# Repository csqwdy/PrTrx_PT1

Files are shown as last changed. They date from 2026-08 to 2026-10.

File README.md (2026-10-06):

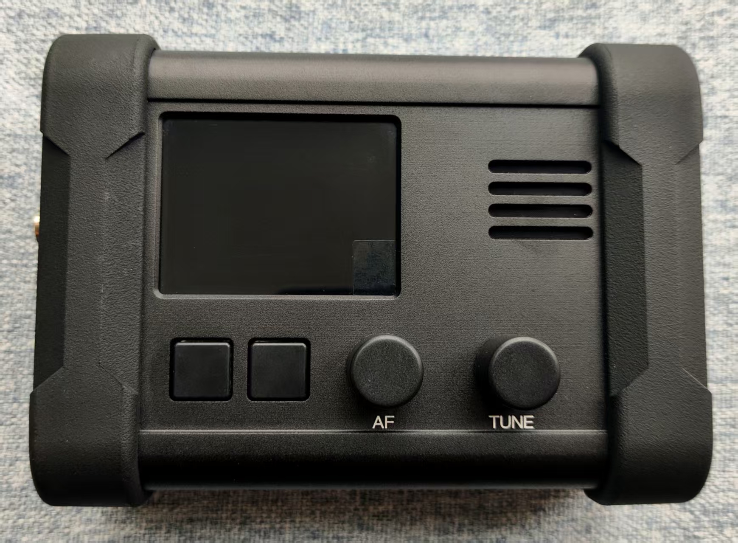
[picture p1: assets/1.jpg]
PrTrx PT正面

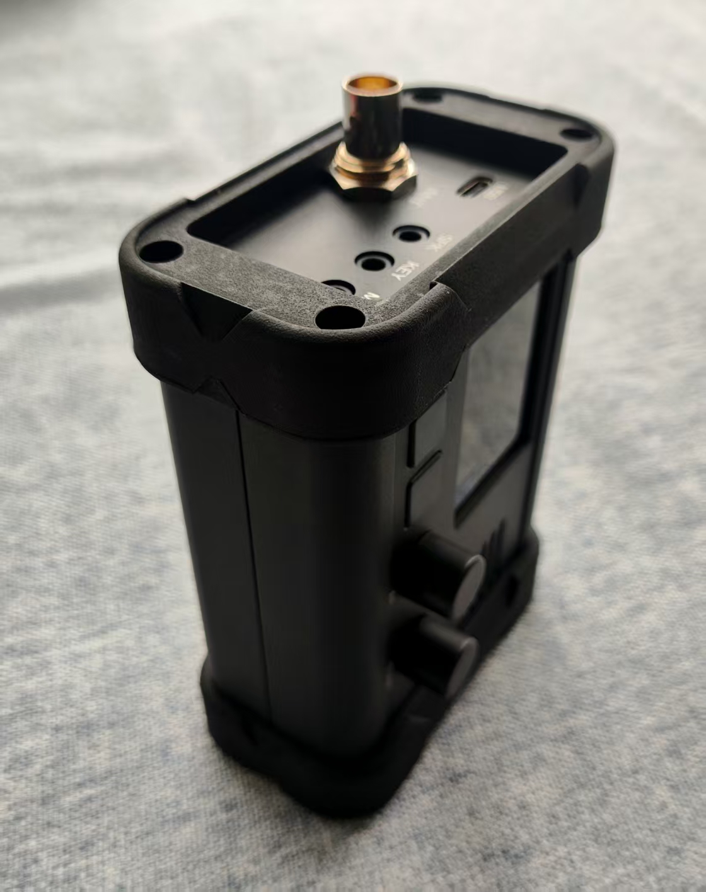
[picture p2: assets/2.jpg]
PrTrx PT正面2


PrTrx PT1 便携式QRP SDR短波电台 开源项目说明
 
一、项目简介
1. PrTrx PT1 是一款紧凑型便携式 QRP SDR 架构业余无线电收发电台。本项目为硬件完全开源、软件闭源授权 的准商业电台性能的开源项目。部分硬件与软件设计参考源自 VK7IAN 开源项目 MBPTRX，且已获得 VK7IAN 正式授权，允许基于 MBPTRX 架构进行二次开发，并允许将部分衍生软件源码进行闭源商用化落地使用。
2. PrTrx PT1 基于 Raspberry Pi Pico2（RP2350）主控的QSD正交采样检波 + QSE正交调制发射 SDR架构。频率覆盖3.5MHz - 30MHz业余无线电短波波段；具备SSB、CW、AM、FM模式；28KHz频谱和瀑布图、降噪NR、噪声消隐NB、陷波Notch滤波器；2.0寸320*240分辨率高清IPS液晶显示屏；
 架构及参数如下：
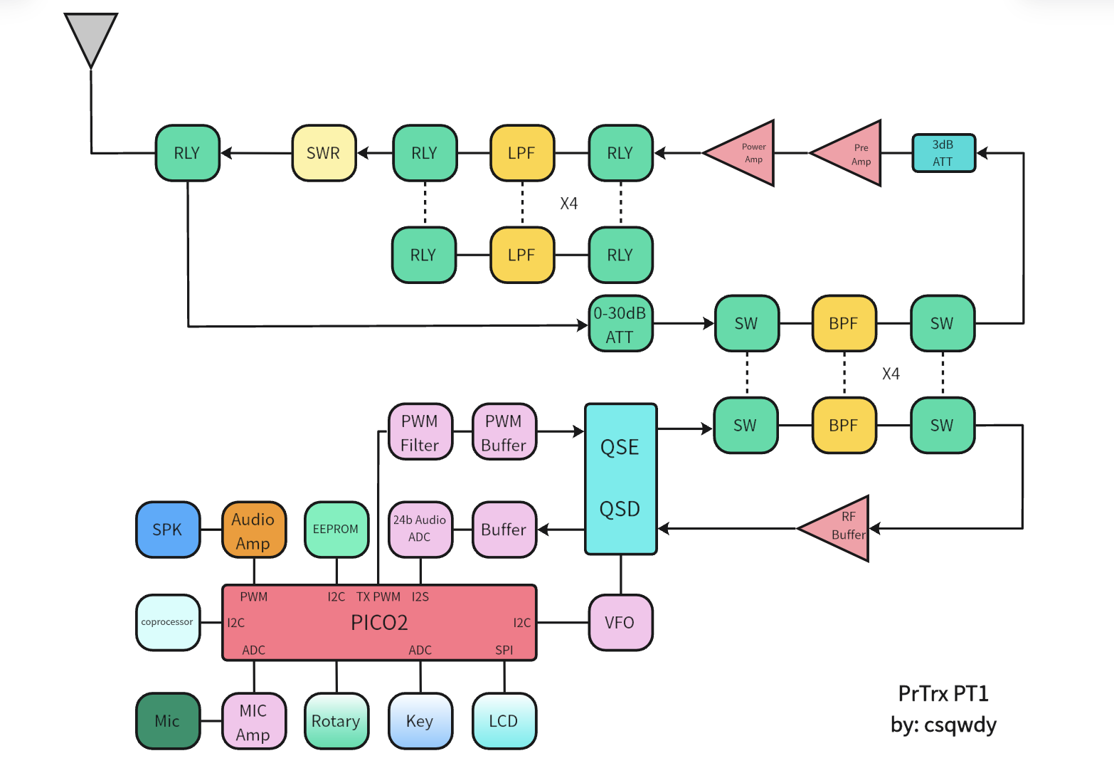
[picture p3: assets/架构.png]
PrTrx PT1架构框图

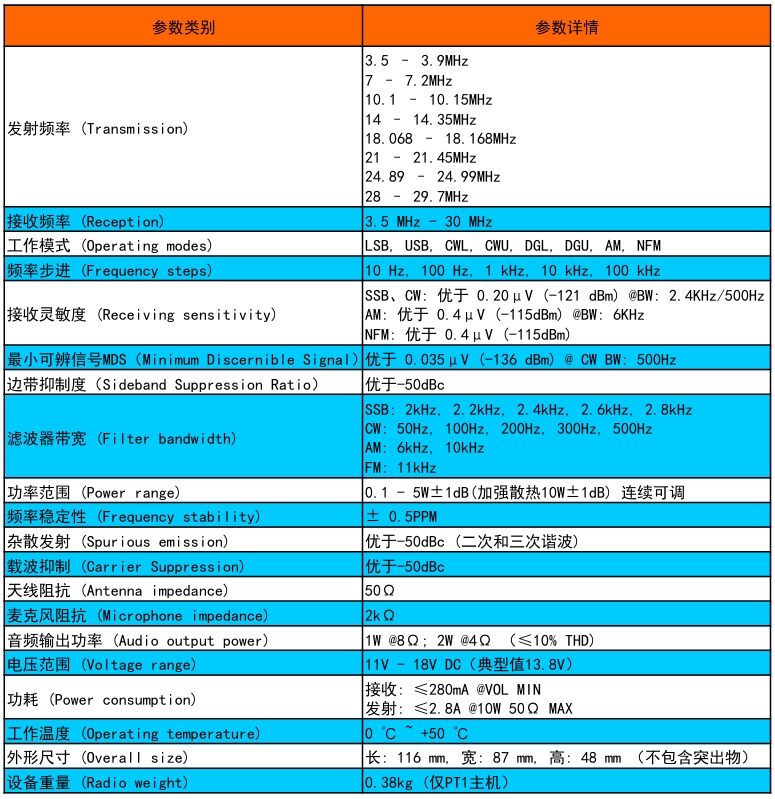
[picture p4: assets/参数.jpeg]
PrTrx PT1参数框图


二、开源授权规则

1. 开放权限:
所有业余无线电爱好者，均可免费查阅、学习、复刻本项目全部开源硬件资料，自主焊接、组装、制作属于个人自用的 PrTrx PT1 电台设备。
2. 使用限制:
禁止任何个人、团队、商家以本项目源码、图纸、改版设备进行任何商业售卖、代工、批量盈利、二次商用包装牟利，仅限个人非商用DIY使用。一经发现违规商用，永久取消项目使用权限并追责。
3. 软件授权规则:
硬件可自由DIY制作，但设备配套运行软件需要单独注册授权。
个人成功组装设备后，可联系项目作者申请专属注册激活码。
 
三、注册码申请

请阅读开源资料中“获取授权.pdf”

四、制作难度与适配人群

本项目属于中高阶硬核硬件DIY项目，电路结构、射频匹配、贴片焊接、参数调试要求较高：
- 不适合新手入门练习；
- 强烈建议具备扎实的模电、射频理论基础，且焊接、硬件调试动手能力极强，并有相关测试仪器的的资深爱好者制作；
- 新手请勿盲目复刻，避免器件浪费、设备无法正常工作。

五、软件、硬件性能限制

1. 为了获取更低的噪音，硬件采用LDO稳压，所以发热高于DC-DC。
2. 为了获取更高的IMD性能，硬件设计限制了发射功率，在10W PEP输出功率下可获得优于-35dBc的IMD3性能（实测为-38dBc）。
3. 为了获取准确的信号强度，低于-120dBm的信号使用多次平均，所以低于-120dBm的信号dBm值显示速度变慢，但低于-130dBm的信号强度仍然难以准确显示。
4. 因为体积限制，散热性能并不出众，在无外部辅助散热的情况下，不建议FT8模式下超过5W使用；如果是常规通联可以放心使用在10W。
5. FM采用相位解调，轻微的相位抖动就会抬高噪声，在使用4Ω/2W扬声器时会造成电源抖动导致相位抖动，本底噪声会抬高2-3dB，所以建议使用8Ω/1W扬声器。

六、最终声明

本项目开源的初衷为推动业余无线电技术交流、纯技术分享、服务个人爱好者DIY，严禁一切商业化行为。所有使用者默认自愿遵守本开源规则，自制设备仅限个人业余通联、学习研究使用。

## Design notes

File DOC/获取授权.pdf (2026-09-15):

# 获取授权

为杜绝商用倒卖、规范个人 DIY 生态，申请授权需提交以下资料：

### 1. 申请人本人合法业余无线电呼号； 2. 本次整机制作对应的 PCB、元器件及其他相关材料的采购订单截图（截图需包含时间及

收货地址，为保护个人信息，地址可部分遮盖）；

### 3. 至少 5 张清晰完整的焊接、组装、调试过程实拍照片（可真实验证为个人手工 DIY）。 4. 硬件组装完毕后，通电并使用 usb 连接电脑，拷贝磁盘名 PrTrx_PT1 中的 STATUS.TXT 和

### REQUEST.TXT；

将以上文件压缩为 zip 格式发送至邮箱：csqwdy@qq.com

### 审核通过后，发放唯一注册码文件 LICENSE.BIN，拷贝 LICENSE.BIN 至磁盘名 PrTrx_PT1 的根

目录完成注册。

### 2026-09-15 补充重要提醒：

1、每个呼号限获取一个注册码文件，批量复刻不予发放注册码文件！ 2、不接受任何形式的团队或组织批量复刻！两人及以上组团或其他形式的批量复刻均拒绝 发放注册码文件！

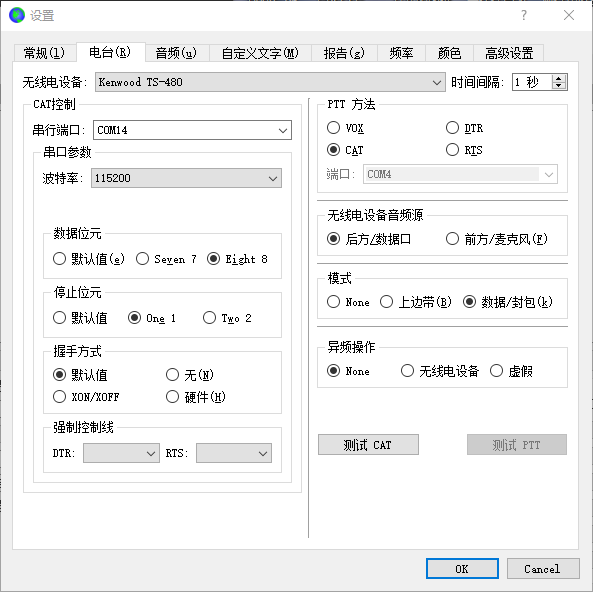
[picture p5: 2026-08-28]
DOC/FT8.png

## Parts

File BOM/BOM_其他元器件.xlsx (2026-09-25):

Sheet: bom模板
 |  |  |  | Bill of Materials | BOM_LCD UNIT V1.0.7_Schematic3_5_2026-08-26
 |  |  |  | Project Title： | PrTrx_开源
 |  |  |  | Variant:
 |  |  |  | Report Time： | 2026年8月26日 19:46:35
No. | Quantity | Comment | Designator | Footprint | Value | Manufacturer | 备注
1 | 1 | 2.0寸ST7789显示屏 |  | 22p正面插脚 |  |  | BGR
2 | 1 | 28mm喇叭 |  | 8欧姆2w
3 | 1 | FPC排线 |  | 20p反向 | 5cm
5 | 1 | 保险丝 |  | 2410 | 3A快断型 | Littelfuse(美国力特)
6 | 300cm | 漆包线 |  | 0.45mm
7 | 5cm | 特富龙镀银线 |  | 0.75mm
8 | 3 | 单头焊片 |  | 孔径3.2mm
10 | 1 | 外壳+TPU护套 |  | K61 | 100mm | 嘉立创
11 | 2 | 旋钮 |  | 12.5*10mm
12 | 2 | 按键帽 |  | 10*10mm | 长短脚
13 | 2 | 带胶塑料垫片 |  | 8mm*0.5mm
14 | 4 | 喇叭防尘网 |  |  |  |  |  | 100
16 | 5 | 双通滚花螺柱 |  | M2 | 8mm |  |  | 50+50
17 | 1 | 双通滚花螺柱 |  | M2 | 6mm
18 | 2 | 单通滚花螺柱 |  | M2 | 6mm |  |  | 200
19 | 4 | 双通滚花螺柱 |  | M2 | 5mm |  |  | 50+50
21 | 9 | 沉头螺丝 |  | M2 | 4mm |  |  | 150+5mmd 100
22 | 13 | 半圆头螺丝 |  | M2 | 4mm |  |  | 300
23 | 2 | 沉头螺丝 |  | M3 | 6mm |  |  | 150
 | 2 | 螺母 |  | M2
26 | 3 | 导热垫 |  | 1cm*1cm | 5mm厚度
27 | 1 | 散热片 |  | 100*45*2.9mm |  |  | 带背胶
28
29
30
31
32

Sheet: Field汇总
Project Title | PrTrx_开源
Borard Title | LCD UNIT V1.0.7
Schematic Title | Schematic3_5
PCB Title | LCD_1.2mm_1.0.7
Variant Name
Total Quantity | 25
Report Time | 19:46:35
Report Date | 2026年8月26日
Report Date&Time | 2026年8月26日 19:46:35
File Name | BOM_LCD UNIT V1.0.7_Schematic3_5_2026-08-26
Filter Option | Add into BOM:no; Convert to PCB:no;

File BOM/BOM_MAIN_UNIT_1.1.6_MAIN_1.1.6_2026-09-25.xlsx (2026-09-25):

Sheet: bom模板
 |  |  |  | Bill of Materials | BOM_MAIN_UNIT_1.1.6_MAIN_1.1.6_2026-09-25
 |  |  |  | Project Title： | PrTrx_开源
 |  |  |  | Variant:
 |  |  |  | Report Time： | 2026年9月25日 16:39:25
No. | Quantity | Comment | Designator | Footprint | Value | Manufacturer Part | Manufacturer | 备注
0 | 35 | 100nF | C1, C2, C4, C5, C6, C7, C11, C19, C21, C23, C35, C39, C41, C42, C44, C45, C49, C50, C52, C53, C54, C79, C82, C86, C88, C91, C92, C93, C94, C95, C99, C101, C102, C103, C104 | C0603 | 100nF |  |  | 50V/±5%/X7R or NP0 C0G
0 | 17 | 10nF | C3, C10, C12, C13, C14, C15, C25, C27, C30, C31, C36, C37, C40, C105, C106, C107, C108 | C0603 | 10nF |  |  | 50V/±5%/X7R or NP0 C0G
0 | 7 | 220nF | C8, C26, C28, C29, C32, C96, C97 | C0603 | 220nF |  |  | 50V/±5%/X7R or NP0 C0G
0 | 2 | 1uF | C9, C43 | C0603 | 1uF |  |  | MIN: 10V
0 | 4 | 100uF | C16, C33, C46, C98 | CAP-SMD_BD5.0-L5.3-W5.3-LS6.3-FD | 100uF |  |  | MIN: 10V
0 | 6 | 270pF | C17, C18, C67, C69, C70, C72 | C0603 | 270pF |  | muRata(村田) | 50V/±5%/NP0 C0G
0 | 5 | 22uF | C20, C22, C24, C38, C100 | C0603 | 22uF |  |  | MIN: 10V
0 | 1 | 390pF | C34 | C0603 | 390pF |  | muRata(村田) | 50V/±5%/NP0 C0G
0 | 9 | 10uF | C47, C48, C51, C80, C81, C83, C84, C90, C109 | C0603 | 10uF |  |  | MIN: 10V
0 | 4 | 1nF | C55, C57, C58, C60 | C0603 | 1nF |  | muRata(村田) | 50V/±5%/NP0 C0G
0 | 3 | 510pF | C56, C64, C66 | C0603 | 510pF |  | muRata(村田) | 50V/±5%/NP0 C0G
0 | 1 | 1.5nF | C59 | C0603 | 1.5nF |  | muRata(村田) | 50V/±5%/NP0 C0G
0 | 3 | 820pF | C61, C63, C65 | C0603 | 820pF |  | muRata(村田) | 50V/±5%/NP0 C0G
0 | 2 | 470pF | C62, C71 | C0603 | 470pF |  | muRata(村田) | 50V/±5%/NP0 C0G
0 | 1 | 180pF | C68 | C0603 | 180pF |  | muRata(村田) | 50V/±5%/NP0 C0G
0 | 4 | 120pF | C73, C75, C76, C78 | C0603 | 120pF |  | muRata(村田) | 50V/±5%/NP0 C0G
0 | 1 | 82pF | C74 | C0603 | 82pF |  | muRata(村田) | 50V/±5%/NP0 C0G
0 | 1 | 220pF | C77 | C0603 | 220pF |  | muRata(村田) | 50V/±5%/NP0 C0G
0 | 3 | PJ-393 8PJ | CN1, CN2, CN3 | AUDIO-TH_PJ-393-8A |  |  | G-Switch(品赞)
0 | 1 | DSS14 | D1 | SOD-123FL_L2.8-W1.8-LS3.6-RD
0 | 1 | BAV99 | D2 | SOT-23-3_L2.9-W1.3-P1.90-LS2.4-BR
0 | 2 | PESD5V0S1BA | D3, D4 | SOD-323_L1.7-W1.3-LS2.5-BI
0 | 1 | KH-CL0.5-H2.0-20PIN | FPC1 | FPC-SMD_KH-CL0.5-H2.0-20PIN |  |  |  | 下接
0 | 1 | HC-PZ200-8.7L-2x5PZ | H1 | HDR-TH_10P-P2.00-V-M-R2-C5-S2.00 |  |  |  | 不需要
0 | 2 | HX PZ1.27-1x8P TP-YQ | H2, H3 | HDR-SMD_8P-P1.27-V-M-LS4.2
0 | 1 | JUMPER-SHORT | JP1 | JUMPER-SHORT
0 | 1 | JUMPER-SPARKFUN | JP2 | JUMPER-SPARKFUN
0 | 4 | 2.2uH | L1, L2, L3, L4 | IND-SMD_L2.9-W2.8 | 2.2uH |  |  | 5%高频电感
0 | 4 | 1.2uH | L5, L6, L7, L8 | IND-SMD_L2.9-W2.8 | 1.2uH |  |  | 5%高频电感
0 | 4 | 680nH | L9, L10, L11, L12 | IND-SMD_L2.9-W2.8 | 680nH |  |  | 5%高频电感
0 | 4 | 330nH | L13, L14, L15, L16 | IND-SMD_L2.9-W2.8 | 330nH |  |  | 5%高频电感
0 | 4 | MPZ1608S601ATA00 | L17, L21, L22, L25 | L0603 |  |  |  | 磁珠，MIN: 1A
0 | 4 | 15uH | L18, L19, L23, L24 | IND-SMD_L1.8-W1.3 | 15uH |  |  | 5%高频电感
0 | 1 | 15uH | L20 | L0805 | 15uH |  |  | 5%高频电感
0 | 1 | 2N7002K | Q1 | SOT-23-3_L2.9-W1.3-P0.95-LS2.4-BR
0 | 16 | 10K | R1, R4, R5, R6, R7, R8, R9, R30, R42, R44, R45, R46, R52, R53, R54, R55 | R0603 | 10K |  |  | 1%,IQ相关需用0.1%
0 | 6 | 4.7K | R2, R3, R20, R22, R25, R26 | R0603 | 4.7K |  |  | 1%,IQ相关需用0.1%
0 | 10 | 100R | R10, R11, R12, R13, R14, R21, R23, R24, R27, R34 | R0603 | 100R |  |  | 1%,IQ相关需用0.1%
0 | 2 | 10R | R15, R28 | R0805 | 10R |  |  | 1%
0 | 5 | 1K | R16, R17, R39, R47, R48 | R0603 | 1K |  |  | 1%,IQ相关需用0.1%
0 | 2 | 18K | R18, R19 | R0603 | 18K |  |  | 1%,IQ相关需用0.1%
0 | 5 | 100K | R29, R32, R33, R35, R38 | R0603 | 100K |  |  | 1%
0 | 3 | 2K | R31, R36, R37 | R0603 | 2K |  |  | 1%
0 | 1 | 560R | R40 | R0603 | 560R |  |  | 1%
0 | 1 | 470R | R41 | R0603 | 470R |  |  | 1%
0 | 1 | 62R | R43 | R0805 | 62R |  |  | 1%
0 | 1 | 49.9R | R57 | R0603 | 49.9R |  |  | 1%
0 | 2 | 6GHz | RX, TX | IPEX-SMD_3P-L2.6-W2.6-LS3.0_MHFIANTENNACONNECTOR | 6GHz | HL2-IPEX1-SMT | HenryTech(恒利泰)
0 | 1 | SH-MX1.25-2PWT | SPK | CONN-SMD_2P-P1.25-2 |  | SH-MX1.25-2PWT | SHOU HAN(首韩)
0 | 1 | Pico 2 | U1 | COMM-SMD_L51.0-W21.0-P2.54_SC0916 |  |  |  | 建议使用第三方type-c接口的
0 | 1 | LMV324IDR | U2 | SOIC-14_L8.7-W3.9-P1.27-LS6.0-BL |  | LMV324IDR | TI(德州仪器)
0 | 1 | PCM1808PWR | U3 | TSSOP-14_L5.0-W4.4-P0.65-LS6.4-BL |  | PCM1808PWR | TI(德州仪器)
0 | 1 | TL974IDR | U4 | SOIC-14_L8.7-W3.9-P1.27-LS6.0-BL-1 |  | TL974IDR | TI(德州仪器)
0 | 3 | FST3253MTCX | U5, U14, U24 | TSSOP-16_L5.0-W4.4-P0.65-LS6.4-BL |  | FST3253MTCX | onsemi(安森美)
0 | 1 | MS5351M | U6 | MSOP-10_L3.0-W3.0-P0.50-LS5.0-BL |  | MS5351M | 杭州瑞盟
0 | 2 | LP5907MFX-3.3/NOPB | U7, U16 | SOT-23-5_L3.0-W1.7-P0.95-LS2.8-BR |  | LP5907MFX-3.3/NOPB | TI(德州仪器)
0 | 1 | NS4160 | U8 | ESOP-8_L4.9-W3.9-P1.27-LS6.0-BL-EP2.0 |  | NS4160 | Nsiway(纳芯威)
0 | 1 | CH32V203G6U6 | U9 | QFN-28_L4.0-W4.0-P0.40-BL-EP2.7 |  | CH32V203G6U6 | WCH(南京沁恒)
0 | 1 | BGA 614 H6327 | U10 | SOT-343-4_L2.0-W1.3-P1.30-LS2.1-BL |  | BGA 614 H6327 | Infineon(英飞凌)
0 | 1 | 26MHz | U11 | OSC-SMD_4P-L2.5-W2.0-BL | 26MHz
0 | 1 | LMV321IDBVR | U12 | SOT-23-5_L3.0-W1.7-P0.95-LS2.8-BR |  | LMV321IDBVR | TI(德州仪器)
0 | 1 | ME6217C33M5G | U13 | SOT-23-5_L3.0-W1.7-P0.95-LS2.8-BR |  | ME6217C33M5G | MICRONE(南京微盟)
0 | 1 | PE4312C-Z | U15 | QFN-20_L4.0-W4.0-P0.50-BL-EP2.2 |  | PE4312C-Z | pSemi(游隼半导体)
0 | 1 | AT24C16C | U23 | SOT-23-5_L3.0-W1.7-P0.95-LS2.8-BL
0 | 1 | 74LVC2G04GW | U25 | SOT-363_L2.1-W1.3-P0.65-LS2.2-BL

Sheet: Field汇总
Project Title | PrTrx_开源
Borard Title | MAIN_UNIT_1.1.6
Schematic Title | Schematic1_12
PCB Title | MAIN_1.1.6
Variant Name
Total Quantity | 231
Report Time | 16:39:25
Report Date | 2026年9月25日
Report Date&Time | 2026年9月25日 16:39:25
File Name | BOM_MAIN_UNIT_1.1.6_MAIN_1.1.6_2026-09-25
Filter Option | Add into BOM:no; Convert to PCB:no;

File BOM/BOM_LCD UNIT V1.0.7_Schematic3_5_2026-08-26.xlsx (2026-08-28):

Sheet: bom模板
 |  |  |  | Bill of Materials | BOM_LCD UNIT V1.0.7_Schematic3_5_2026-08-26
 |  |  |  | Project Title： | PrTrx_开源
 |  |  |  | Variant:
 |  |  |  | Report Time： | 2026年8月26日 19:46:35
No. | Quantity | Comment | Designator | Footprint | Value | Manufacturer | 备注
1 | 4 | 100nF | C1, C3, C5, C6 | C0603 |  |  | 50V/±5%/X7R or NP0 C0G
2 | 2 | 22uF | C2, C4 | C0603 |  |  | MIN: 10V
3 | 1 | 10uF | C7 | C0603 |  |  | MIN: 10V
4 | 3 | 10nF | C8, C9, C10 | C0603 |  |  | 50V/±5%/X7R or NP0 C0G
5 | 1 | 100uF | C46 | CAP-SMD_BD5.0-L4.5 |  |  | MIN: 10V
6 | 1 | 1N4148WS | D1 | SOD-323_L1.7-W1.3-LS2.7-RD
7 | 1 | FPC0521-22PH20 | FPC1 | FPC-SMD_FPC0521-22PH20
8 | 1 | 10R | R1 | R0805 |  |  | 1%
9 | 1 | 5R1 | R2 | R0603 |  |  | 1%
10 | 1 | 10K | R3 | R0603 |  |  | 1%
11 | 1 | 10kΩ | R4 | RES-ADJ-TH_RK09K1130AJ3 |  | ALPSALPINE(阿尔卑斯阿尔派)
12 | 1 | 10k | R5 | R0603 |  |  | 1%
13 | 1 | EC11 | SW1 |  |  |  | 30定位15脉冲
14 | 2 | 12x12x7.3 | SW2, SW3 | SW-TH_4P-L12.0-W12.0-P5.00-LS12.5
15 | 1 | 6206P33 | U1 | SOT-89-3_L4.5-W2.4-P1.50-LS4.0-BR
16 | 2 | PM1.27-1x8P | U2, U3 | HDR-TH_8P-P1.27-V-F-2
17

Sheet: Field汇总
Project Title | PrTrx_开源
Borard Title | LCD UNIT V1.0.7
Schematic Title | Schematic3_5
PCB Title | LCD_1.2mm_1.0.7
Variant Name
Total Quantity | 25
Report Time | 19:46:35
Report Date | 2026年8月26日
Report Date&Time | 2026年8月26日 19:46:35
File Name | BOM_LCD UNIT V1.0.7_Schematic3_5_2026-08-26
Filter Option | Add into BOM:no; Convert to PCB:no;

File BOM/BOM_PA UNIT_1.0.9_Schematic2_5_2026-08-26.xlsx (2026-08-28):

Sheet: bom模板
 |  |  |  | Bill of Materials | BOM_PA UNIT_1.0.9_Schematic2_5_2026-08-26
 |  |  |  | Project Title： | PrTrx_开源
 |  |  |  | Variant:
 |  |  |  | Report Time： | 2026年8月26日 19:59:59
No. | Quantity | Comment | Designator | Footprint | Value | Manufacturer | 备注
1 | 2 | 220uF | C1, C27 | CAP-SMD_BD6.3-L6.6-W6.6-LS7.3-FD |  |  | MIN: 25V
2 | 27 | 100nF | C2, C3, C6, C7, C10, C11, C13, C14, C15, C16, C20, C22, C23, C24, C26, C28, C29, C30, C47, C50, C51, C52, C55, C56, C57, C62, C64 | C0603 |  |  | 50V/±5%/X7R or NP0 C0G
3 | 5 | 220uF | C4, C5, C8, C9, C12 | CAP-SMD_BD6.3-L6.6-W6.6-LS7.3-FD |  |  | MIN: 16V
4 | 1 | 10uF | C17 | C0603 |  |  | MIN: 10V
5 | 2 | 10uF | C18, C21 | C0805 |  |  | MIN: 25V
6 | 5 | 10nF | C19, C25, C48, C49, C65 | C0603 |  |  | 50V/±5%/X7R or NP0 C0G
7 | 4 | 680pF | C31, C34, C36, C37 | C0603 |  |  | MIN: 100V/NP0 C0G
8 | 2 | 1.2nF | C32, C33 | C0603 |  |  | MIN: 100V/NP0 C0G
9 | 2 | 390pF | C35, C38 | C0603 |  |  | MIN: 100V/NP0 C0G
10 | 4 | 220pF | C39, C42, C44, C45 | C0603 |  |  | MIN: 100V/NP0 C0G
11 | 2 | 360pF | C40, C41 | C0603 |  |  | MIN: 100V/NP0 C0G
12 | 2 | 120pF | C43, C46 | C0603 |  |  | MIN: 100V/NP0 C0G
13 | 2 | N/A | C53, C54 | C0603
14 | 2 | 10nF | C58, C59 | C0805 |  |  | MIN: 100V/NP0 C0G
15 | 1 | 180pF | C60 | C1206 |  |  | MIN: 250V/NP0 C0G
16 | 2 | N/A | C61, C63 | C0805
17 | 2 | 1N5711WS-7-F | D1, D2 | SOD-323_L1.8-W1.3-LS2.5-RD |  | DIODES(美台)
18 | 1 | 01550900M | FH1 | FUSE-SMD_L9.8-W5.0_01550900M |  | Littelfuse(美国力特)
19 | 1 | MLD-FPC-05L-20P-H20 | FPC1 | FPC-SMD_0.5K-A-20PB-RXW
20 | 2 | MPZ1608S601ATA00 | L1, L15 | L0603 |  | TDK
21 | 1 | 6*10-3.0T | L2
22 | 2 | T37-2/23T | L3, L5 | T37 |  | MICROMETAL
23 | 1 | T37-2/24T | L4 | T37 |  | MICROMETAL
24 | 3 | T37-2/15T | L6, L7, L8 | T37 |  | MICROMETAL
25 | 2 | T37-6/12T | L9, L11 | T37 |  | MICROMETAL
26 | 1 | T37-6/13T | L10 | T37 |  | MICROMETAL
27 | 1 | T37-6/9T | L12 | T37 |  | MICROMETAL
28 | 2 | T37-6/10T | L13, L14 | T37 |  | MICROMETAL
29 | 2 | 15uH | L16, L17 | L0603 |  | muRata(村田)
30 | 1 | CJ7809 | LDO1 | TO-252-2_L6.6-W6.1-P4.58-LS10.1-BR-CW |  | CJ(江苏长电/长晶)
31 | 2 | CJ7805 | LDO2, LDO3 | TO-252-2_L6.6-W6.1-P4.58-LS10.1-BR-CW |  | CJ(江苏长电/长晶)
32 | 2 | XR70P03D | Q1, Q2 | DFN-8_L3.0-W3.0-P0.65-BL-4
33 | 2 | 2N7002K | Q3, Q6 | SOT-23-3_L2.9-W1.3-P0.95-LS2.4-BR
34 | 1 | AO3401 | Q4 | SOT-23-3_L2.9-W1.3-P0.95-LS2.4-BR
35 | 2 | RD16HHF1 | Q5, Q7 |  |  | Mitsubishi Group(三菱)
36 | 3 | 100K | R1, R2, R5 | R0603 |  |  | 1%
37 | 1 | 47K | R3 | R0603 |  |  | 1%
38 | 5 | 10K | R4, R6, R28, R30, R32 | R0603 |  |  | 1%
39 | 2 | 2.2R | R7, R20 | R0805 |  |  | 1%
40 | 2 | 4.7R | R8, R16 | R0603 |  |  | 1%
41 | 2 | 2kΩ | R9, R19 | RES-ADJ-SMD_303-13
42 | 2 | 470R | R10, R11 | R0603 |  |  | 1%
43 | 2 | 130R | R12, R13 | R0603 |  |  | 1%
44 | 6 | 1K | R14, R18, R27, R29, R33, R34 | R0603 |  |  | 1%
45 | 2 | 470R | R15, R17 | R1206 |  |  | 1%
46 | 4 | 100R | R21, R22, R23, R24 | R1206 |  |  | 1%
47 | 2 | 7.5K | R25, R26 | R0603 |  |  | 1%
48 | 1 | 39K | R31 | R0603 |  |  | 1%
49 | 1 | 17.4R | R35 | R0603 |  |  | 1%
50 | 2 | 294R | R36, R37 | R0603 |  |  | 1%
51 | 2 | 2K | R38, R39 | R0603 |  |  | 1%
52 | 1 | DS801FPS0317 | RF1 |  |  | dosinconn(德索五金)
53 | 2 | IPEX | RX, TX | IPEX-SMD_3P-L2.6-W2.6-LS3.0_MHFIANTENNACONNECTOR
54 | 2 | TC4-1T+ | T1, T2 | XFMR-SMD_TC1-1TX |  | Mini-Circuits
55 | 1 | BN43-202 | T3 |  |  | Amidon
56 | 1 | DC-042C-Z-2.0 | U1 | DC-IN-TH_DC-042C-Z-2.0 |  | XKB Connection(中国星坤)
57 | 1 | GEK100-13 | U2 | TSOT23-6_L2.9-W1.6-P0.95-LS2.8-BL
58 | 1 | GR7533HS | U3 | SOT-23-3_L2.9-W1.6-P1.90-LS2.8-TL
59 | 1 | FXCM7060F-501T | U4 | FILTER-SMD_4P-L7.0-W6.0-BL |  | cjiang(长江微电)
60 | 1 | OPA2677N | U5 | SOIC-14_L8.7-W3.9-P1.27-LS6.0-BL |  | TI(德州仪器)
61 | 5 | G6K-2F-Y-5V | U6, U8, U9, U10, U11 | RELAY-SMD_G6K-2F-Y |  | OMRON(欧姆龙)
62 | 1 | ULN2003A | U7 | SOP-16_L10.0-W3.9-P1.27-LS6.0-BL |  | UMW(友台半导体)
63 | 1 | BN43-302 | U12 |  |  | Amidon
64 | 1 | ZX-MX1.25-2PLT | U13 | CONN-SMD_2P-P1.25-MX1.25-2P-LT
65

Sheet: Field汇总
Project Title | PrTrx_开源
Borard Title | PA UNIT_1.0.9
Schematic Title | Schematic2_5
PCB Title | PA_1.0.9
Variant Name
Total Quantity | 154
Report Time | 19:59:59
Report Date | 2026年8月26日
Report Date&Time | 2026年8月26日 19:59:59
File Name | BOM_PA UNIT_1.0.9_Schematic2_5_2026-08-26
Filter Option | Add into BOM:no; Convert to PCB:no;

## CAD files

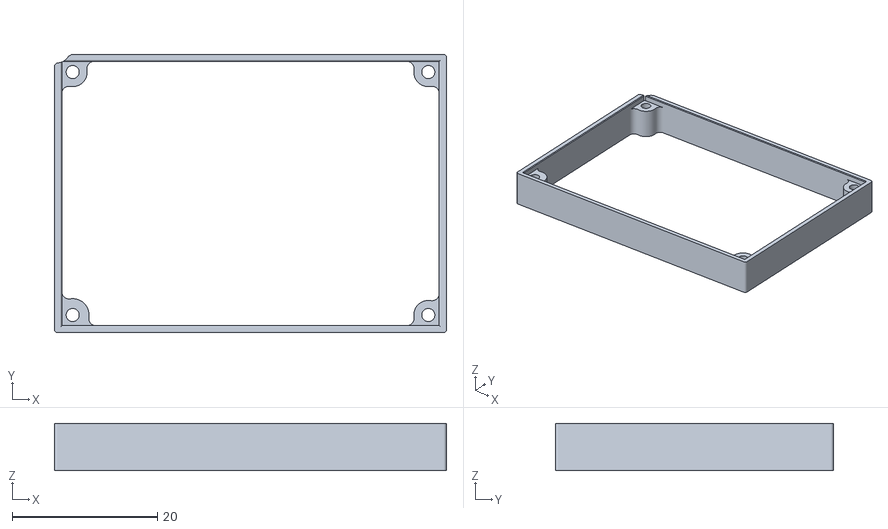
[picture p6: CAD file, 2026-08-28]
STL/PrTrx液晶屏支架.stl
53.9 x 38.3 x 6.50

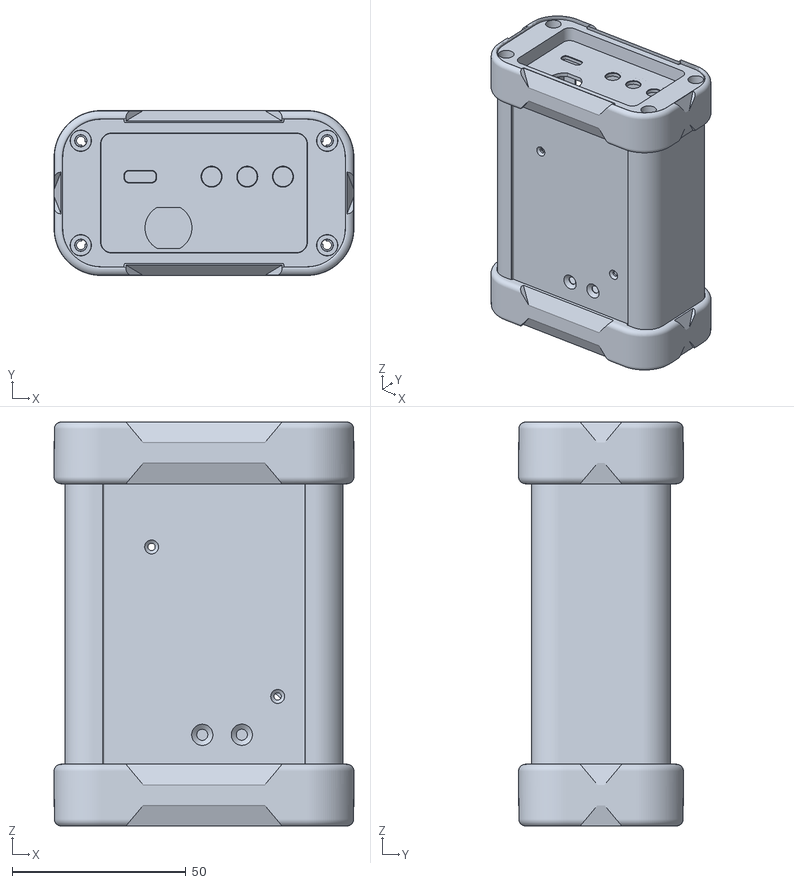
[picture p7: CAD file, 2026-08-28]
STL/PrTrx开源_嘉立创K61外壳.stl
86.4 x 47.5 x 116.4

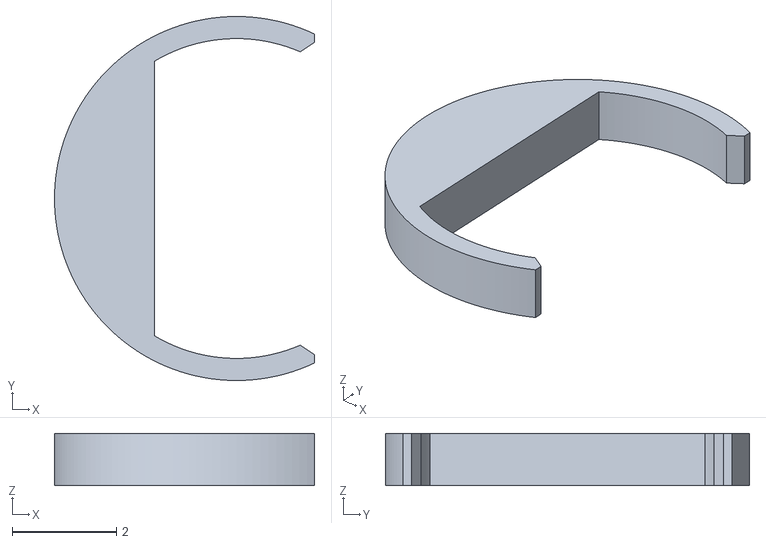
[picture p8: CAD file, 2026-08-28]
STL/垫高.stl
5.00 x 7.00 x 1.00

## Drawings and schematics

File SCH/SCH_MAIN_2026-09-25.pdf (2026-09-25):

2B1 | 10 2B2 | 11 2B3 | 12 2B4 | 13 S0 | 14 OE2# | 15 VCC | 16

# 4-8MHz

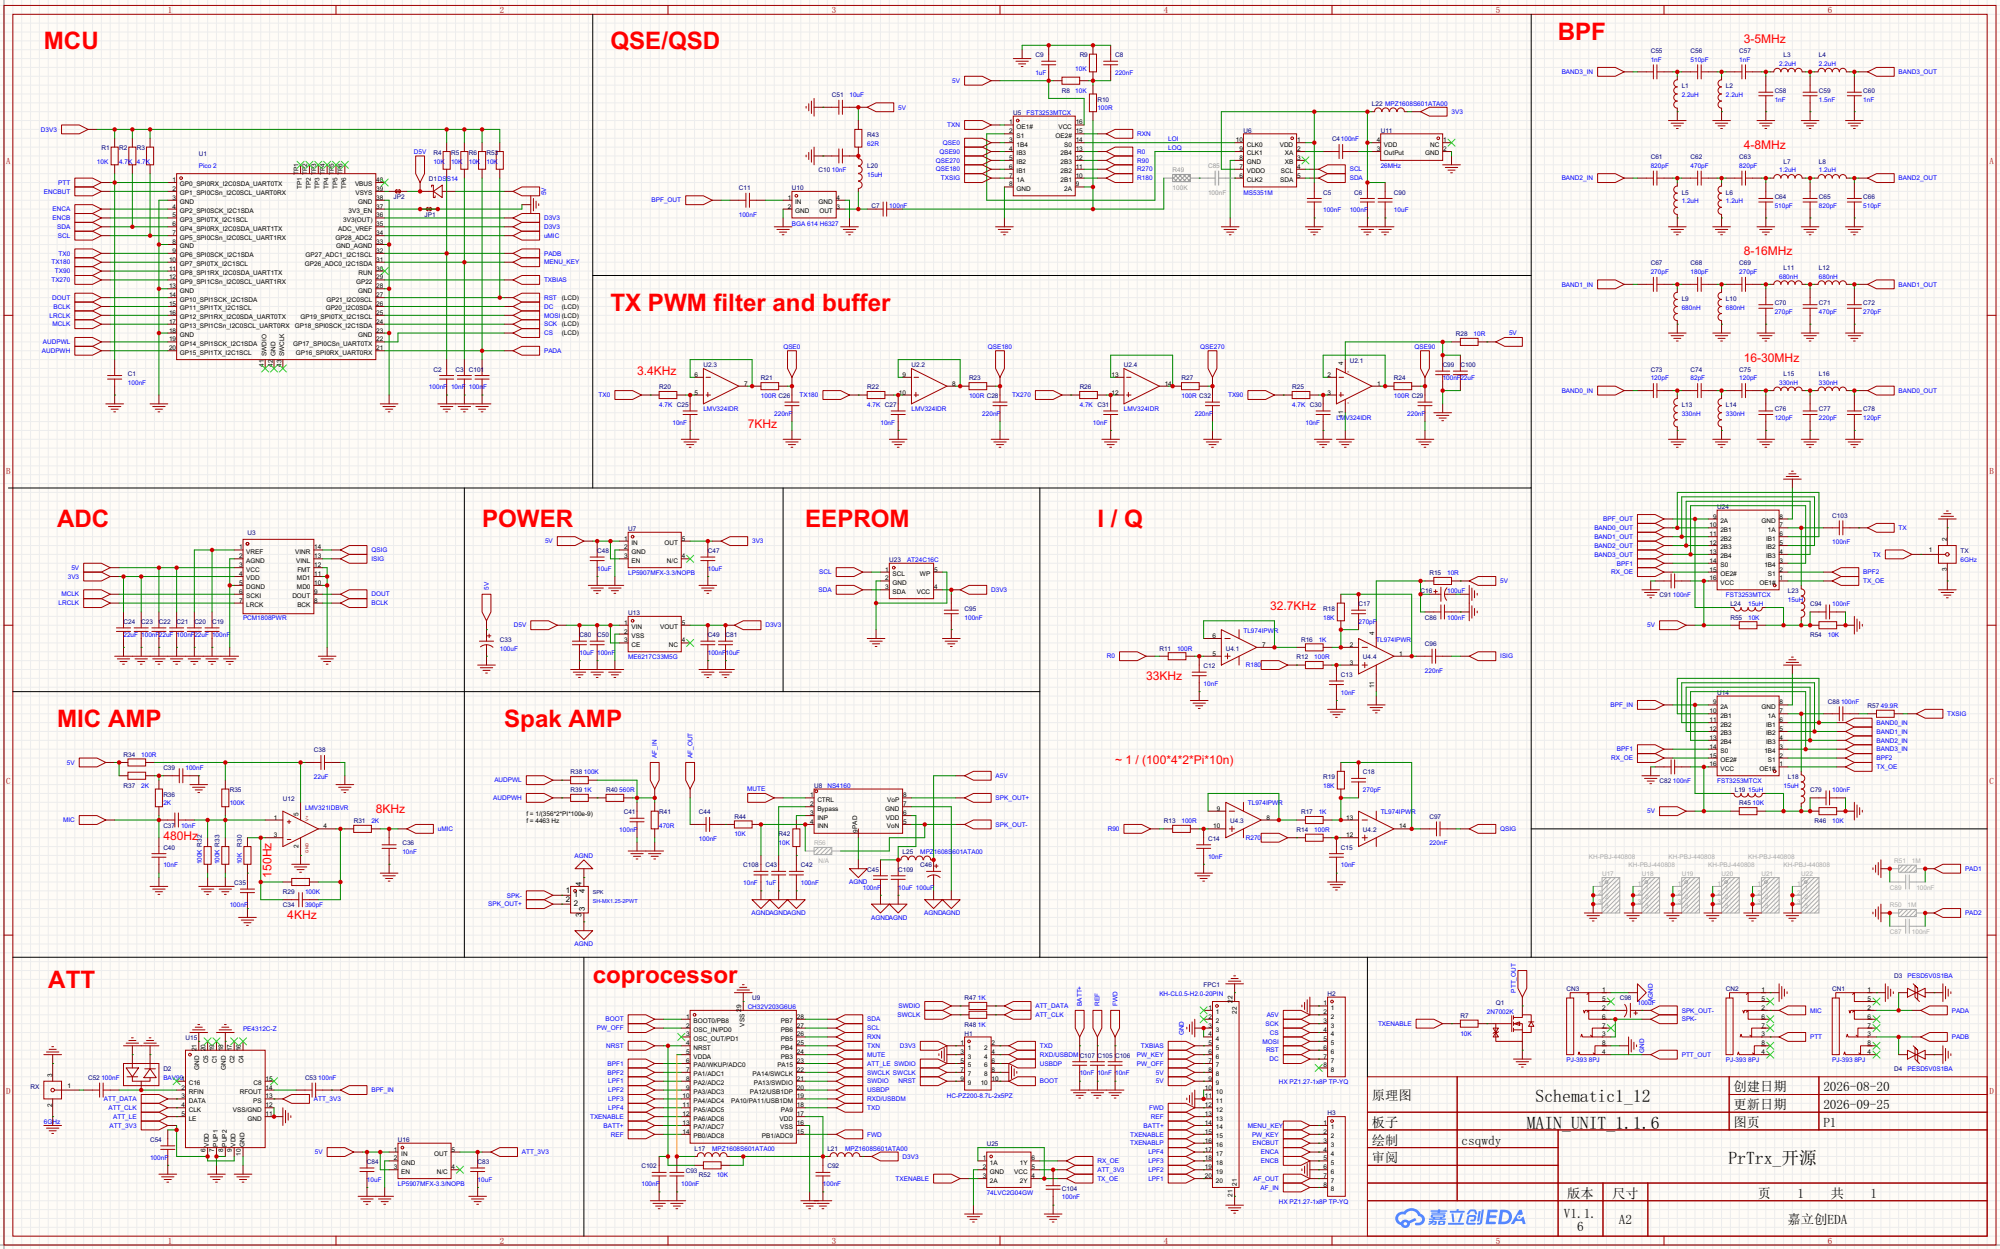
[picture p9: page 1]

PADB
MENU_KEY
TX PWM filter and buffer

10 11 12 13 14 15 16 | 9 | 2A 2B1 2B2 2B3 2B4 S0 OE2# VCC FST3253MTCX | L24 R55 | 15uH 10K | GND OE1# | 1A IB1 IB2 IB3 1B4 S1 | 8 7 6 5 4 3 2 1 | L23 15uH

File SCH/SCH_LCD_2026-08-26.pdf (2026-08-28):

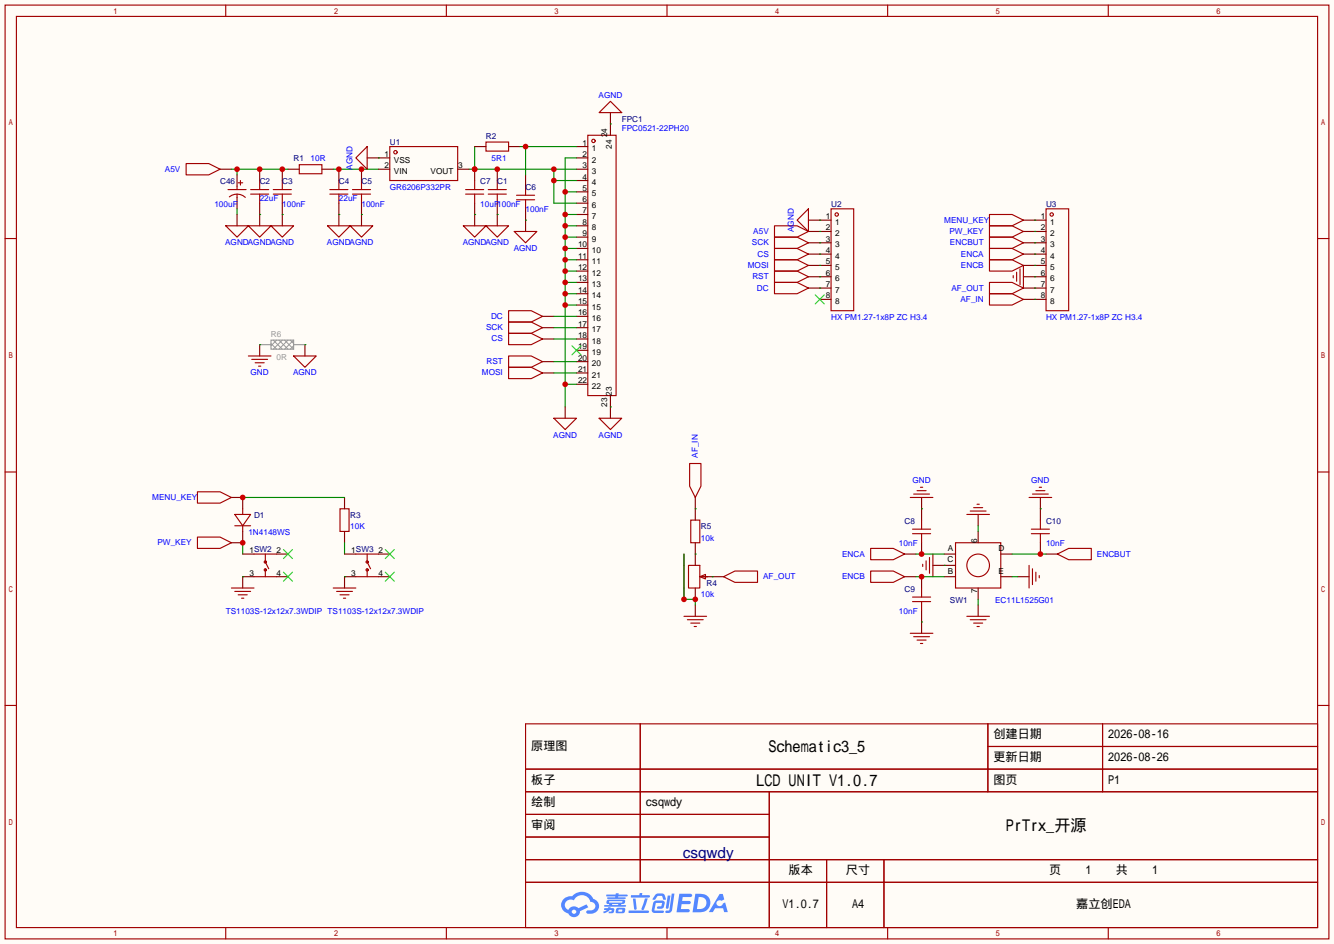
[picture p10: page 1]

原理图 | Schematic3_5 | 创建日期 | 2026-08-16

更新日期 | 2026-08-26

板子 | LCD UNIT V1.0.7 | 图页 | P1

绘制 | csqwdy | PrTrx_开源
审阅

csqwdy

V1.0.7 | A4 | 嘉立创EDA

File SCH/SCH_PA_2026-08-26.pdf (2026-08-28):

+

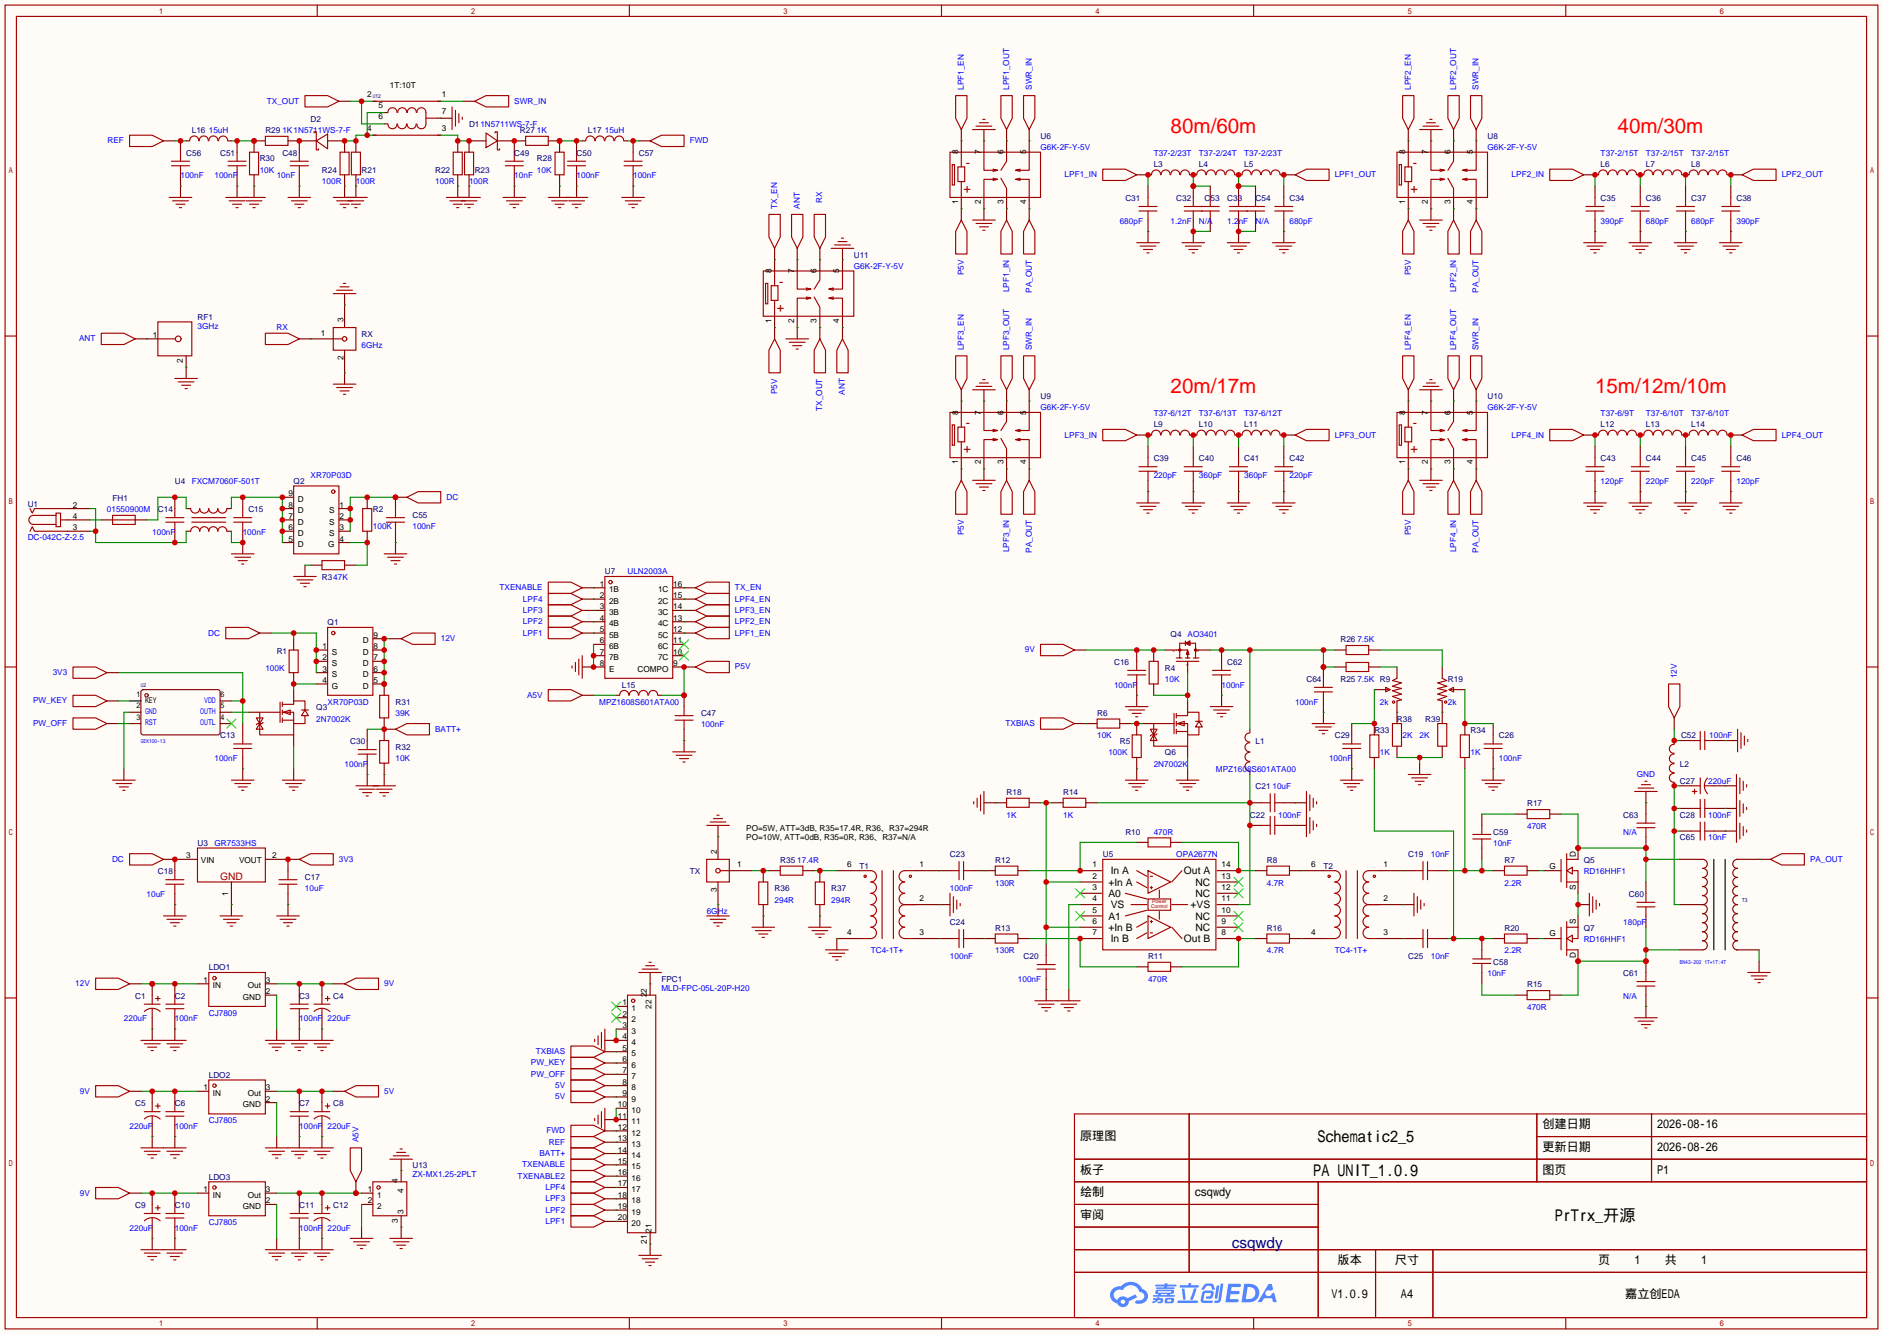
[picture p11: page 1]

原理图 | Schematic2_5 | 创建日期 | 2026-08-16

更新日期 | 2026-08-26

板子 | PA UNIT_1.0.9 | 图页 | P1

绘制 | csqwdy | PrTrx_开源
审阅

csqwdy

V1.0.9 | A4 | 嘉立创EDA
